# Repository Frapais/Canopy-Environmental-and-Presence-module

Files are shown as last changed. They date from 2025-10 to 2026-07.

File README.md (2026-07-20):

# Canopy — Environmental & Presence Module

**Canopy** is an expansion module from the **SprigStack** ecosystem. It plugs directly onto the pin headers of a [**Sprig-C3**](https://github.com/Frapais/Sprig-C3) ESP32-C3 development board and turns it into a complete, battery-powered environmental and presence sensor for Home Assistant.

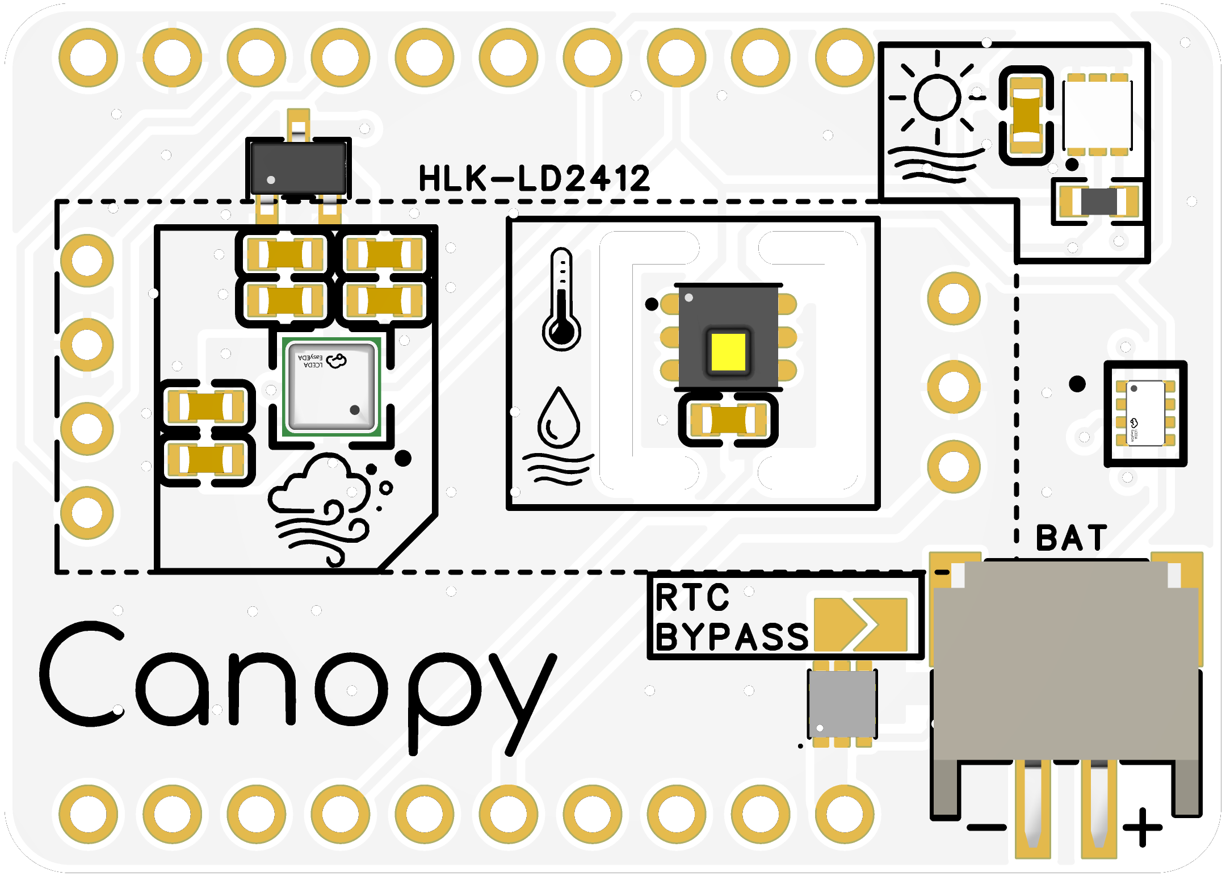
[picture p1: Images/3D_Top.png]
Canopy top side
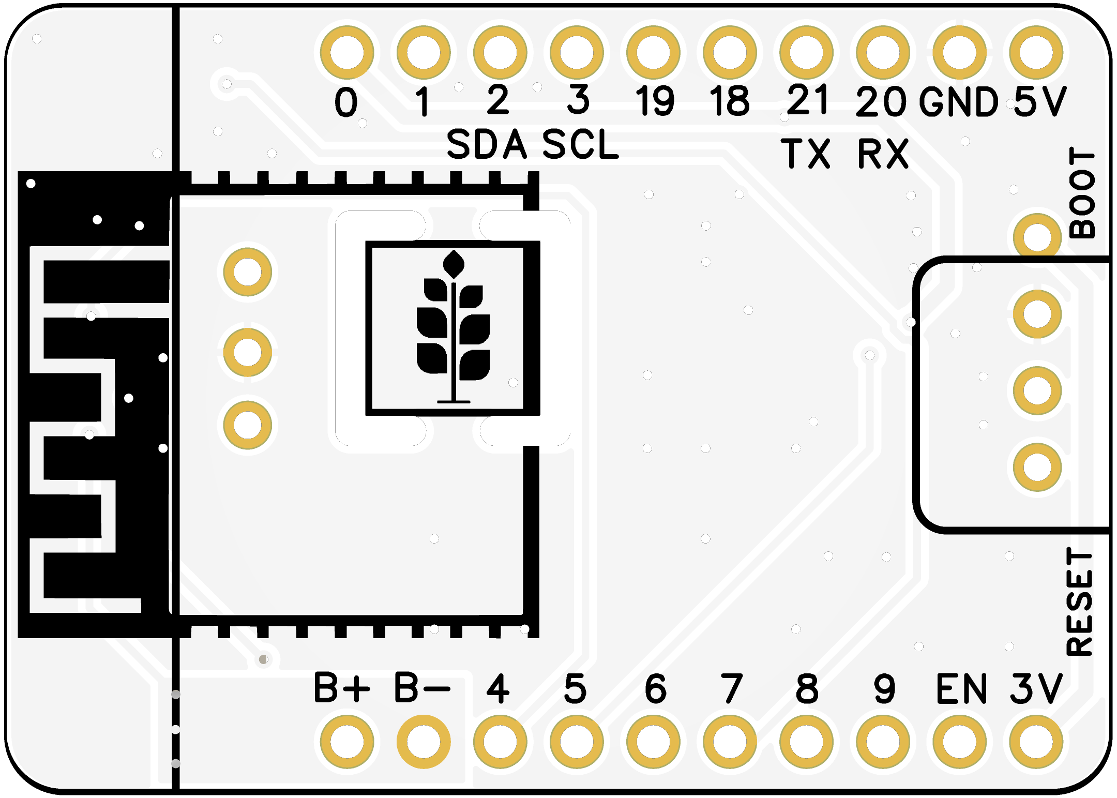
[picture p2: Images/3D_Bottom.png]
Canopy bottom side
|  |  |
| --- | --- |
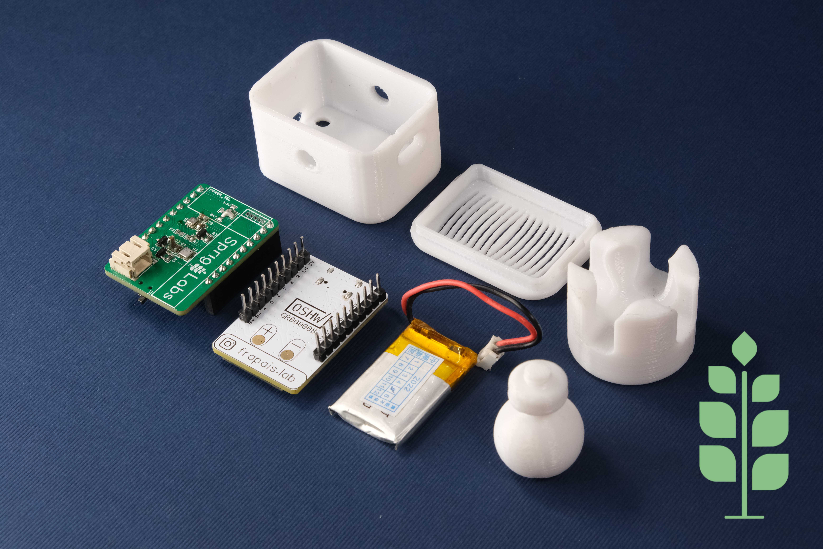
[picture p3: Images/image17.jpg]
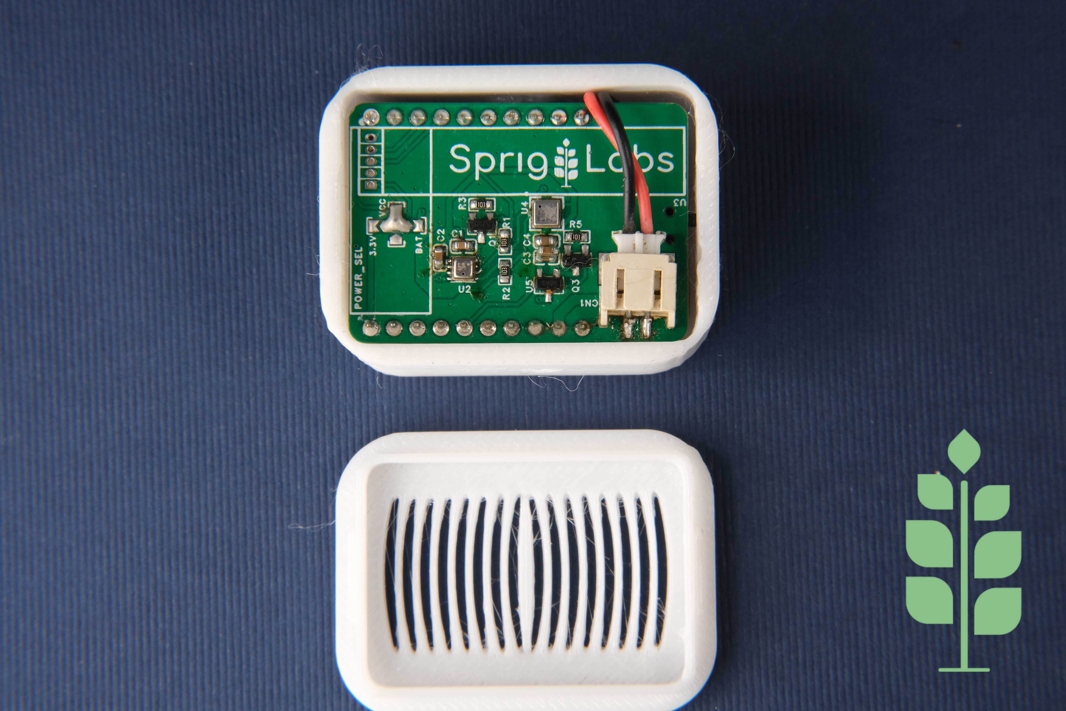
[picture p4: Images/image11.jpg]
|  |  |

---

## Contents

- [Features](#features)
- [Sensors](#sensors)
- [Pinout](#pinout)
- [Power management](#power-management)
- [Real-time clock](#real-time-clock)
- [Enclosure](#enclosure)
- [Firmware](#firmware)
  - [ESPHome setup](#esphome-setup)
  - [MQTT setup](#mqtt-setup)
- [Repository structure](#repository-structure)
- [Availability](#availability)
- [Support](#support)
- [License](#license)

---

## Features

- Air temperature and relative humidity
- Air quality: **AQI**, **eCO₂** and **TVOC**
- Ambient light in lux
- 24 GHz **mmWave human presence** detection, including stationary targets (NOT implemented yet)
- On-board **real-time clock** with a solder-jumper bypass (NOT implemented yet)
- Independent **power gating** of every sensor via GPIO, for true low-power deep-sleep operation
- Secondary **battery connector** passed through to the Sprig-C3
- Stacks directly onto the Sprig-C3 / C6 headers — no wiring
- Designed to fit the 3D-printed ball-joint enclosure included in this repo

---

## Sensors

| Function | Part | Interface | Address | Power enable |
| --- | --- | --- | --- | --- |
| Air temperature & humidity | HDC1080 | I²C | `0x40` | GPIO **8** |
| Air quality (AQI / eCO₂ / TVOC) | ENS160 | I²C | `0x53` | GPIO **0** |
| Ambient light | VEML6030 | I²C | `0x48` | GPIO **7** |
| Human presence | HLK-LD2412 | UART | — | <!-- TODO: enable pin, or always-on --> |
| Real-time clock | <!-- TODO: part number --> | I²C | <!-- TODO --> | always on (see [RTC](#real-time-clock)) |
| Battery gauge | MAX17048 *(on the Sprig-C3)* | I²C | `0x36` | always on |

> The VEML6030 responds at `0x48` when its ADDR pin is pulled high and `0x10` when pulled low. The ENS160 responds at `0x53` or `0x52` in the same way. Run an I²C scan on first power-up to confirm what your board reports.

---

## Pinout

Canopy uses the following Sprig-C3 pins. **Every other pin on the headers is passed straight through** and remains free for your own use.

| Sprig-C3 pin | Used for |
| --- | --- |
| 2 | I²C **SDA** — all I²C sensors + RTC + fuel gauge |
| 3 | I²C **SCL** |
| 8 | HDC1080 power enable (active high) |
| 0 | ENS160 power enable (active high) |
| 7 | VEML6030 power enable (active high) |
| 20 / 21 | HLK-LD2412 **RX / TX** <!-- TODO: confirm orientation --> |
| 3V3, GND | Module supply |



### Strapping-pin note

GPIO **8** is a strapping pin on the ESP32-C3 and must read high at reset. It is an input for the first few hundred milliseconds after power-up, so if the HDC1080 rail pulls it low during that window the board will not boot. GPIO **9** (BOOT) and GPIO **2** (SDA, held high by the bus pull-ups) are the other two strapping pins. GPIO **0** and **7** are unrestricted.

---

## Power management

Each environmental sensor is fed from a GPIO rather than the main 3V3 rail, so firmware can cut its supply entirely before entering deep sleep. Combined with the Sprig-C3's ~66 µA idle draw, this is what makes multi-month battery life realistic.

```
digitalWrite(PWR_HDC1080,  HIGH);   // GPIO 8
digitalWrite(PWR_ENS160,   HIGH);   // GPIO 0
digitalWrite(PWR_VEML6030, HIGH);   // GPIO 7
delay(50);                          // let the rails settle before I²C
```

Two things to keep in mind:

- **The ENS160 needs warm-up time.** Its gas readings are only meaningful after roughly 3 minutes of continuous operation, and the sensor requires a one-time 24-hour burn-in when new. Power-gating it on a short cycle means it never leaves warm-up, so keep it powered for update intervals below ~10 minutes.
- **GPIO 7 and 8 are not RTC-capable** on the ESP32-C3, so they float during deep sleep. Call `gpio_deep_sleep_hold_en()` and `gpio_hold_en()` on them before sleeping, or those rails will drift.

---

## Real-time clock (NOT implemented yet)

Canopy carries an on-board RTC so the node can enter deep-sleep cycles that completely shut down the system, therefore achieving great battery life. <!-- TODO: solder the RTC and test its functionality -->

The **RTC BYPASS** solder jumper on the board.

---

## Enclosure

The `Enclosure/` folder contains a two-part sensor housing and a matching ball-joint mount, so the module can be aimed at whatever the mmWave sensor should be watching.

| Part | File | Size (mm) |
| --- | --- | --- |
| Enclosure body | `Env sensor enclosure - Body.stl` | 32.1 × 42.8 × 24.4 |
| Enclosure lid | `Env sensor enclosure - Lid.stl` | 32.1 × 42.8 × 6.0 |
| Ball (attaches to body) | `Ball Joint - ball.stl` | 20.0 × 20.0 × 29.4 |
| Mount cup (attaches to surface) | `Ball Joint - mount.stl` | 30.0 × 30.0 × 23.0 |
| Full assembly | `Assembly.step` | — |

### Printing

| Setting | Recommendation |
| --- | --- |
| Material | PLA or PETG |
| Layer height | 0.1-0.20 mm |
| Walls | 2 perimeters |
| Infill | 10% |
| Supports | Not required for the body or lid; the ball joint prints best stem-up |

The vented face of the lid must stay clear — it is the airflow path to the HDC1080 and ENS160. Do not fill it with supports or paint over it. The lid is deliberately thin in front of the mmWave module so the 24 GHz signal passes through; avoid metallic or carbon-filled filaments, which will block it.

<!-- TODO: hardware list — screw size and count for lid, whether the ball is a friction fit or needs a screw -->

---

## Firmware

Two paths are supported. ESPHome is the fastest way to get entities into Home Assistant; the Arduino/MQTT sketch is for anyone who wants full control or is not running ESPHome.

### ESPHome setup

**Requirements:** Home Assistant with the ESPHome add-on installed.

1. Plug the Canopy onto the Sprig-C3, then connect the Sprig-C3 to the machine running Home Assistant while holding **BOOT** (only needed the first time).
2. In ESPHome, add a new device and pick **ESP32-C3**.
3. Replace the generated YAML with the contents of [`Firmware/canopy-test.yaml`](Firmware/canopy-test.yaml).
4. Set `wifi_ssid` and `wifi_password` in your ESPHome `secrets.yaml`.
5. Upload, selecting the port that appears as a **USB JTAG** device.
6. Configure the newly discovered device from Home Assistant settings.

### MQTT setup

**Requirements:** an MQTT broker (tested with Mosquitto) and the Home Assistant MQTT integration, plus the Arduino IDE.

1. Open [`Firmware/Canopy_C3_mqtt/Canopy_C3_mqtt.ino`](Firmware/Canopy_C3_mqtt/Canopy_C3_mqtt.ino).
2. Install the required libraries from the Library Manager:
   - PubSubClient (Nick O'Leary)
   - ArduinoJson v6.x (Benoit Blanchon)
   - Adafruit MAX1704X
   - ClosedCube HDC1080
   - SparkFun Indoor Air Quality Sensor — ENS160
   - SparkFun Ambient Light Sensor (VEML6030)
3. Select **ESP32C3 Dev Module** as the board and upload.
4. On first boot the node opens an open WiFi access point named **`Canopy-Setup`**. Join it from a phone or laptop; the captive portal appears automatically, or browse to `http://192.168.4.1`.
5. Enter your WiFi credentials and MQTT broker address, port, username and password, then save. The node reboots and connects.
6. Entities appear in Home Assistant automatically through MQTT discovery — no manual topic entry needed. All readings are published every 60 seconds to `canopy/<device-id>/state` as a single JSON payload, with availability on `canopy/<device-id>/status`.

Hold the **BOOT** button for 5 seconds at any point to erase the stored credentials and reopen the setup portal.

---

## Repository structure

```
Canopy-Environmental-and-Presence-module/
├── README.md
├── LICENSE
├── PCB/
│   ├── Canopy-schematic.pdf          # exported schematic, readable without EDA software
│   ├── Canopy-BOM.csv                # bill of materials
│   ├── Gerbers/                      # zipped fabrication files
│   ├── EasyEDA/                      # source project files
│   └── Images/                       # renders: top, bottom, pinout
├── Firmware/
│   ├── ESPHome/
│   │   └── canopy.yaml               # full ESPHome configuration
│   └── MQTT/
│       └── Canopy_C3_mqtt/
│           └── Canopy_C3_mqtt.ino    # standalone Arduino sketch with setup portal
└── Enclosure/
    ├── Env sensor enclosure - Body.stl
    ├── Env sensor enclosure - Lid.stl
    ├── Ball Joint - ball.stl
    ├── Ball Joint - mount.stl
    ├── Assembly.step
    └── Images/                       # renders of the assembled unit
```

---

## Availability

Assembled Canopy modules and Sprig-C3 boards are available from [Tindie](https://www.tindie.com/products/spriglabs/canopy-smart-environmental-sensor/), [Lectronz](https://lectronz.com/products/canopy-smart-environmental-sensor), and the [Sprig Labs store](https://sprig-labs.com/canopy).

---

## Support

If you find this project useful, consider supporting its development:

- [PayPal](https://www.paypal.com/paypalme/kostasparaskevas)
- [Buy Me a Coffee](https://www.buymeacoffee.com/spriglabs)
- Instagram: [@sprig_labs](https://www.instagram.com/sprig_labs/)
- YouTube: [@sprig_labs](https://www.youtube.com/@sprig_labs)

---

## License

Released under the **GPL-3.0** license. See [LICENSE](LICENSE).

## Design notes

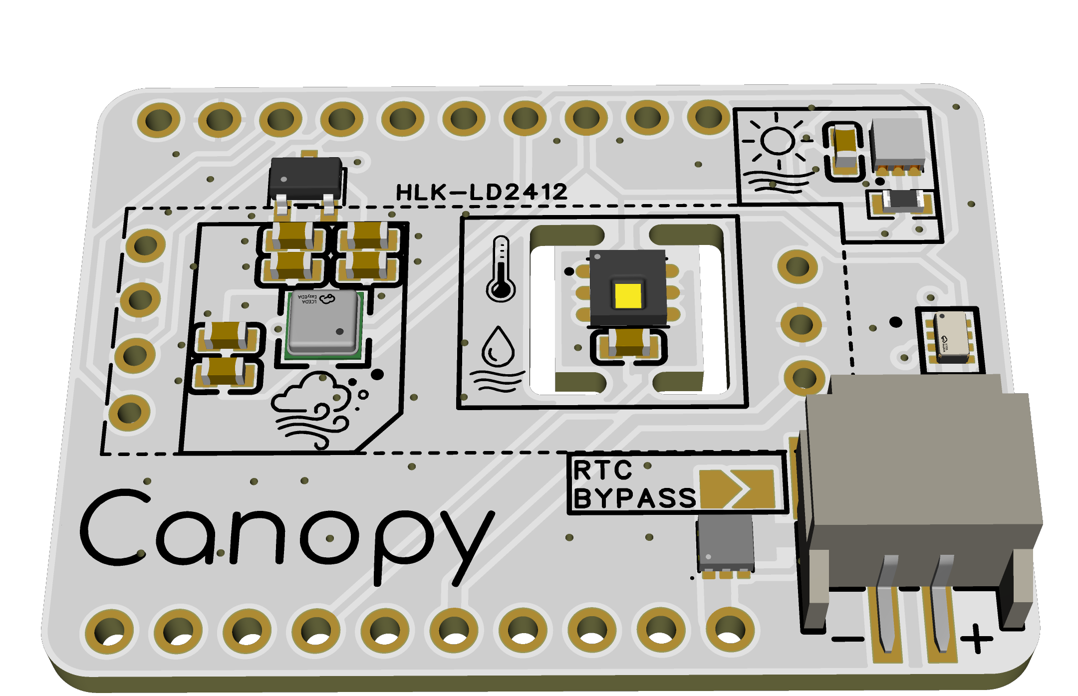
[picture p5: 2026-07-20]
Images/3D.png

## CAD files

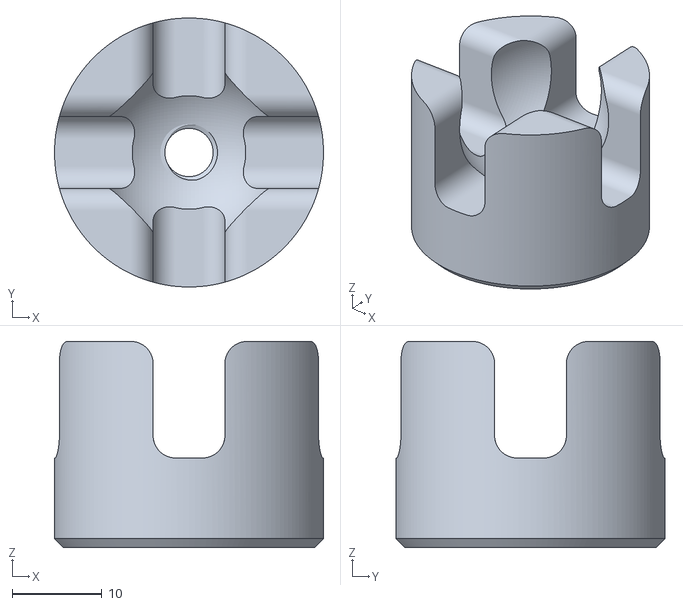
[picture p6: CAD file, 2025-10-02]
Enclosure/Ball Joint - mount.stl
30.0 x 30.0 x 23.0

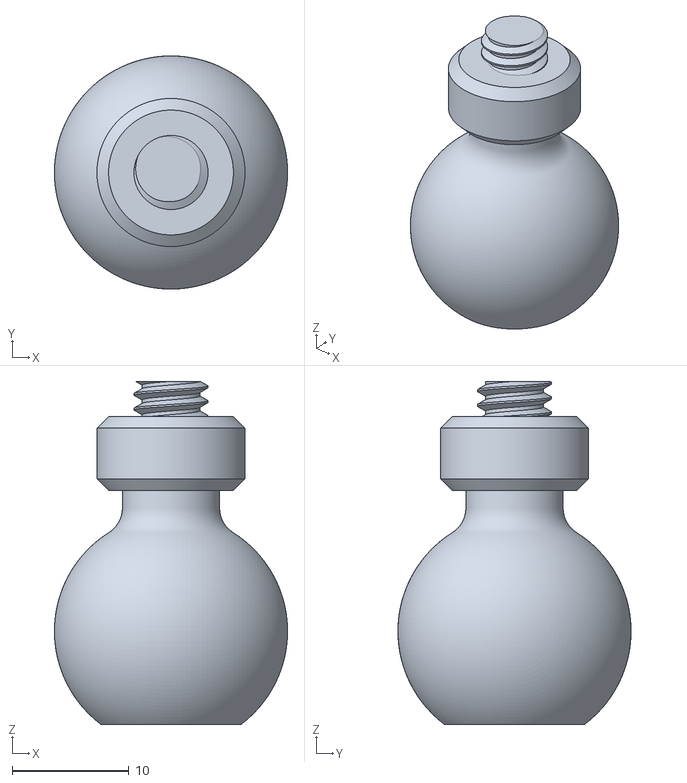
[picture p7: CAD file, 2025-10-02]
Enclosure/Ball Joint - ball.stl
20.0 x 20.0 x 29.4

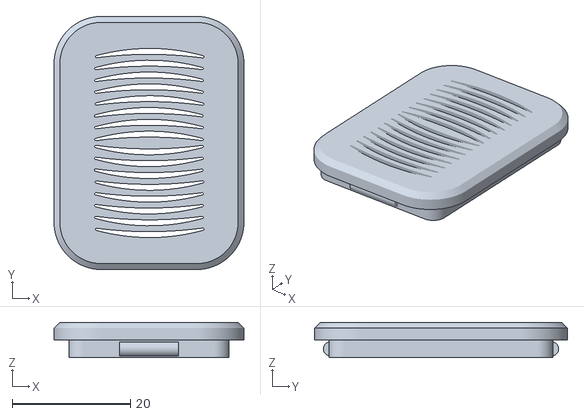
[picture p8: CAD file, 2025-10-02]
Enclosure/Env sensor enclosure - Lid.stl
32.1 x 42.8 x 6.00

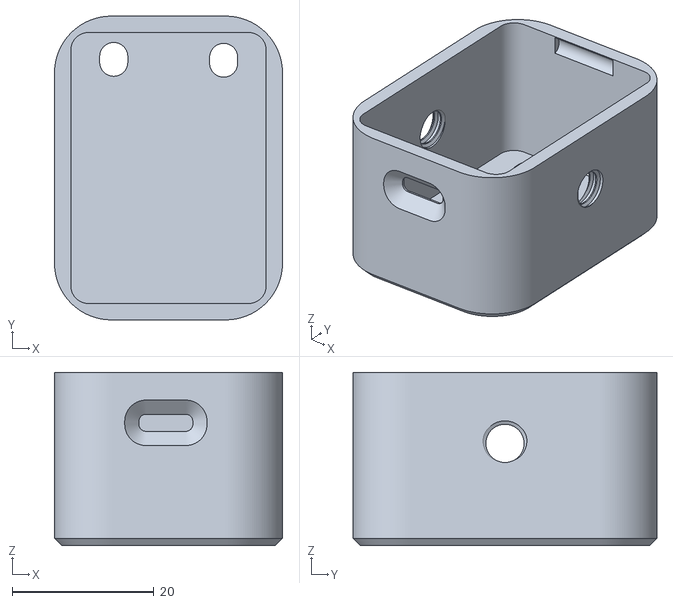
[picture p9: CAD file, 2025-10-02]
Enclosure/Env sensor enclosure - Body.stl
32.1 x 42.8 x 24.4

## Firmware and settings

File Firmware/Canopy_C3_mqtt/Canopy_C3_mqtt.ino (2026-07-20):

/*
 * Canopy + Sprig-C3 — MQTT environmental node
 * ------------------------------------------------------------------
 * Hardware:
 *   Sprig-C3 (ESP32-C3) + Canopy expansion PCB
 *   I2C bus on SDA=GPIO2, SCL=GPIO3
 *     0x36  MAX17048  fuel gauge   (on the Sprig-C3 itself)
 *     0x40  HDC1080   temp / RH    (power via GPIO8)
 *     0x53  ENS160    eCO2 / TVOC  (power via GPIO0)
 *     0x48  VEML6030  ambient lux  (power via GPIO7)
 *
 * Behaviour:
 *   First boot (or after factory reset) -> opens the "Canopy-Setup" AP with a
 *   captive portal at 192.168.4.1 where the user enters WiFi + MQTT details.
 *   Credentials are stored in NVS; on later boots the node connects, publishes
 *   Home Assistant MQTT discovery, then publishes all readings every 60 s.
 *
 *   Hold BOOT (GPIO9) for 5 s at any time to wipe credentials and reopen
 *   the setup portal.
 *
 * Required libraries (Library Manager names):
 *   PubSubClient                        by Nick O'Leary
 *   ArduinoJson  (v6.x)                 by Benoit Blanchon
 *   Adafruit MAX1704X                   by Adafruit
 *   ClosedCube HDC1080                  by ClosedCube
 *   SparkFun Ambient Light Sensor Arduino Library (VEML6030)
 *
 *   The ENS160 is driven by direct register access (see the ENS160 section
 *   below) rather than through a library, so its full status word can be
 *   reported instead of a pass/fail boolean.
 *
 * Board: "ESP32C3 Dev Module" (esp32 core 2.0.x / 3.x)
 */

#include <WiFi.h>
#include <WebServer.h>
#include <DNSServer.h>
#include <Preferences.h>
#include <PubSubClient.h>
#include <ArduinoJson.h>
#include <Wire.h>

#include "Adafruit_MAX1704X.h"
#include "ClosedCube_HDC1080.h"
#include "SparkFun_VEML6030_Ambient_Light_Sensor.h"

// ------------------------------------------------------------------
//  User-tunable settings
// ------------------------------------------------------------------
#define SDA_PIN            2
#define SCL_PIN            3

#define PWR_HDC1080        8      // GPIO powering the HDC1080
#define PWR_ENS160         0      // GPIO powering the ENS160
#define PWR_VEML6030       7      // GPIO powering the VEML6030

#define BOOT_BTN           9      // Sprig-C3 BOOT button, active low
#define BOOT_HOLD_MS       5000   // hold time for factory reset

#define PUBLISH_INTERVAL   60000UL   // ms between publishes
#define WIFI_TIMEOUT_MS    20000UL   // give up and open the portal after this

#define VEML6030_ADDR      0x48   // 0x48 if ADDR is high, 0x10 if ADDR is low
#define ENS160_ADDR        0x53   // 0x53 if ADDR is high, 0x52 if ADDR is low

// The ENS160 needs ~3 min of warm-up after every power-up before its gas
// readings mean anything, so with a 60 s interval it is left powered on.
// Set this to false only if you switch to a long deep-sleep cycle.
#define KEEP_SENSORS_POWERED   true

// Print the full ENS160 register dump on every publish cycle.
// Set to false once the sensor is behaving.
#define ENS_VERBOSE            true

const char *AP_SSID = "Canopy-Setup";
const char *AP_PASS = "";          // open AP; set an 8+ char password to secure it
const char *FW_VERSION = "1.0";

// ------------------------------------------------------------------
//  Globals
// ------------------------------------------------------------------
Adafruit_MAX17048   maxlipo;
ClosedCube_HDC1080  hdc1080;
SparkFun_Ambient_Light veml(VEML6030_ADDR);

WiFiClient   wifiClient;
PubSubClient mqtt(wifiClient);
WebServer    server(80);
DNSServer    dnsServer;
Preferences  prefs;

// stored configuration
String cfgSsid, cfgPass, cfgMqttHost, cfgMqttUser, cfgMqttPass;
int    cfgMqttPort = 1883;
String cfgDeviceName = "Canopy";

// runtime state
bool  portalMode      = false;
bool  discoverySent   = false;
bool  hdcOk = false, ensOk = false, vemlOk = false, fuelOk = false;
char  devUniqueID[32];
String baseTopic, stateTopic, availTopic, deviceIP;
unsigned long lastPublish = 0;
unsigned long bootPressStart = 0;
float vemlGain = 0.125;     // low gain suits indoor + daylight without saturating
int   vemlIntegTime = 100;  // ms

// ------------------------------------------------------------------
//  Sensor power control
// ------------------------------------------------------------------
void sensorsPower(bool on) {
  digitalWrite(PWR_HDC1080,  on ? HIGH : LOW);
  digitalWrite(PWR_ENS160,   on ? HIGH : LOW);
  digitalWrite(PWR_VEML6030, on ? HIGH : LOW);
  if (on) delay(50);   // let the rails settle before touching I2C
}

// ------------------------------------------------------------------
//  ENS160 register-level access
//  Datasheet register map, all multi-byte values little-endian.
// ------------------------------------------------------------------
#define ENS_PART_ID   0x00   // 2 bytes, should read 0x0160
#define ENS_OPMODE    0x10   // 0x00 deep sleep, 0x01 idle, 0x02 standard, 0xF0 reset
#define ENS_CONFIG    0x11
#define ENS_TEMP_IN   0x13   // 2 bytes, (degC + 273.15) * 64
#define ENS_RH_IN     0x15   // 2 bytes, %RH * 512
#define ENS_STATUS    0x20
#define ENS_DATA_AQI  0x21
#define ENS_DATA_TVOC 0x22   // 2 bytes, ppb
#define ENS_DATA_ECO2 0x24   // 2 bytes, ppm
#define ENS_DATA_T    0x30   // 2 bytes, compensation readback
#define ENS_DATA_RH   0x32   // 2 bytes, compensation readback

uint8_t ensAddr = ENS160_ADDR;

bool ensAcks(uint8_t addr) {
  Wire.beginTransmission(addr);
  return Wire.endTransmission() == 0;
}

bool ensRead(uint8_t reg, uint8_t *buf, uint8_t len) {
  Wire.beginTransmission(ensAddr);
  Wire.write(reg);
  if (Wire.endTransmission(false) != 0) return false;
  if (Wire.requestFrom((int)ensAddr, (int)len) != (int)len) return false;
  for (uint8_t i = 0; i < len; i++) buf[i] = Wire.read();
  return true;
}

uint8_t ensRead8(uint8_t reg) {
  uint8_t v = 0;
  ensRead(reg, &v, 1);
  return v;
}

uint16_t ensRead16(uint8_t reg) {
  uint8_t b[2] = {0, 0};
  ensRead(reg, b, 2);
  return (uint16_t)b[0] | ((uint16_t)b[1] << 8);
}

bool ensWrite8(uint8_t reg, uint8_t val) {
  Wire.beginTransmission(ensAddr);
  Wire.write(reg);
  Wire.write(val);
  return Wire.endTransmission() == 0;
}

bool ensWrite16(uint8_t reg, uint16_t val) {
  Wire.beginTransmission(ensAddr);
  Wire.write(reg);
  Wire.write((uint8_t)(val & 0xFF));
  Wire.write((uint8_t)(val >> 8));
  return Wire.endTransmission() == 0;
}

// Feed temperature / humidity to the ENS160 for gas compensation.
void ensSetCompensation(float tempC, float rhPct) {
  ensWrite16(ENS_TEMP_IN, (uint16_t)((tempC + 273.15f) * 64.0f));
  ensWrite16(ENS_RH_IN,   (uint16_t)(rhPct * 512.0f));
}

const char *ensValidityText(uint8_t v) {
  switch (v) {
    case 0: return "normal";
    case 1: return "warm-up";
    case 2: return "initial start-up";
    default: return "invalid output";
  }
}

// Put the part into standard measuring mode from whatever state it is in.
bool ensStartStandard() {
  ensWrite8(ENS_OPMODE, 0xF0);   // reset
  delay(20);
  ensWrite8(ENS_OPMODE, 0x01);   // idle
  delay(20);
  bool ok = ensWrite8(ENS_OPMODE, 0x02);   // standard
  delay(50);
  return ok && ensRead8(ENS_OPMODE) == 0x02;
}

void ens160Diagnostics() {
  Serial.println(F("---------- ENS160 diagnostics ----------"));
  Serial.print(F("  uptime           : "));
  Serial.print(millis() / 1000);
  Serial.println(F(" s since boot"));

  // 1. Does anything answer on the bus?
  if (!ensAcks(ensAddr)) {
    Serial.print(F("  I2C              : NO ACK at 0x"));
    Serial.println(ensAddr, HEX);
    uint8_t alt = (ensAddr == 0x53) ? 0x52 : 0x53;
    Serial.print(F("  alternate 0x"));
    Serial.print(alt, HEX);
    Serial.println(ensAcks(alt) ? F("     : RESPONDS -> set ENS160_ADDR to this")
                                : F("     : no response either"));
    Serial.println(F("  => The chip is not on the bus. Check that GPIO0 is high,"));
    Serial.println(F("     that the 3V3 rail at the sensor is really 3.3 V under"));
    Serial.println(F("     load, and that SDA/SCL pull-ups are present."));
    Serial.println(F("----------------------------------------"));
    return;
  }
  Serial.print(F("  I2C              : ACK at 0x"));
  Serial.println(ensAddr, HEX);

  // 2. Is it actually an ENS160?
  uint16_t pid = ensRead16(ENS_PART_ID);
  Serial.print(F("  PART_ID          : 0x"));
  Serial.print(pid, HEX);
  Serial.println(pid == 0x0160 ? F("  (correct)")
                               : F("  (EXPECTED 0x160 - wrong device or bad reads)"));

  // 3. What mode is it in?
  uint8_t opmode = ensRead8(ENS_OPMODE);
  Serial.print(F("  OPMODE           : 0x"));
  Serial.print(opmode, HEX);
  switch (opmode) {
    case 0x00: Serial.println(F("  DEEP SLEEP - not measuring")); break;
    case 0x01: Serial.println(F("  IDLE - not measuring")); break;
    case 0x02: Serial.println(F("  STANDARD - measuring")); break;
    case 0xF0: Serial.println(F("  RESET")); break;
    default:   Serial.println(F("  unexpected value")); break;
  }

  // 4. Decode the status word.
  uint8_t st = ensRead8(ENS_STATUS);
  uint8_t validity = (st >> 2) & 0x03;
  Serial.print(F("  STATUS           : 0x"));
  if (st < 0x10) Serial.print('0');
  Serial.println(st, HEX);
  Serial.print(F("    STATAS (running) : ")); Serial.println((st & 0x80) ? F("yes") : F("NO"));
  Serial.print(F("    STATER (error)   : ")); Serial.println((st & 0x40) ? F("YES") : F("no"));
  Serial.print(F("    VALIDITY         : ")); Serial.print(validity);
  Serial.print(F(" = ")); Serial.println(ensValidityText(validity));
  Serial.print(F("    NEWDAT           : ")); Serial.println((st & 0x02) ? F("yes") : F("no"));
  Serial.print(F("    NEWGPR           : ")); Serial.println((st & 0x01) ? F("yes") : F("no"));

  // 5. Raw measurement registers, regardless of NEWDAT.
  Serial.print(F("  DATA_AQI         : ")); Serial.println(ensRead8(ENS_DATA_AQI) & 0x07);
  Serial.print(F("  DATA_TVOC        : ")); Serial.print(ensRead16(ENS_DATA_TVOC)); Serial.println(F(" ppb"));
  Serial.print(F("  DATA_ECO2        : ")); Serial.print(ensRead16(ENS_DATA_ECO2)); Serial.println(F(" ppm"));

  // 6. Confirm the compensation values actually landed.
  uint16_t rawT = ensRead16(ENS_DATA_T);
  uint16_t rawH = ensRead16(ENS_DATA_RH);
  Serial.print(F("  comp readback    : "));
  Serial.print(rawT / 64.0f - 273.15f, 1); Serial.print(F(" C, "));
  Serial.print(rawH / 512.0f, 1); Serial.println(F(" %RH"));

  // 7. Plain-language conclusion.
  Serial.print(F("  => "));
  if (st == 0x00 || st == 0xFF) {
    Serial.println(F("Status reads all-zero/all-ones: the chip acknowledges its"));
    Serial.println(F("     address but is not responding properly. Almost always a"));
    Serial.println(F("     power problem - see the GPIO0 note in the README."));
  } else if (opmode != 0x02) {
    Serial.println(F("Not in STANDARD mode, so it will never produce data."));
    Serial.println(F("     The mode write was lost, usually because the rail dropped."));
  } else if (st & 0x40) {
    Serial.println(F("Error flag set. Power-cycle GPIO0 and re-check."));
  } else if (validity == 3) {
    Serial.println(F("Invalid output. Usually a brown-out mid-measurement or a"));
    Serial.println(F("     sensor element fault."));
  } else if (validity == 1) {
    Serial.println(F("Warming up. Gas data becomes valid ~3 min after power-on."));
  } else if (validity == 2) {
    Serial.println(F("Initial start-up. This lasts up to 1 hour and happens once"));
    Serial.println(F("     in the sensor's life. Values are published but coarse."));
  } else {
    Serial.println(F("Operating normally."));
  }
  Serial.println(F("----------------------------------------"));
}

// ------------------------------------------------------------------
//  Sensor init
// ------------------------------------------------------------------
void initSensors() {
  // --- MAX17048 fuel gauge (always powered, lives on the Sprig-C3) ---
  fuelOk = maxlipo.begin(&Wire);
  if (fuelOk) {
    Serial.print(F("MAX17048 chip ID: 0x"));
    Serial.println(maxlipo.getChipID(), HEX);
  } else {
    Serial.println(F("MAX17048 not found."));
  }

  // --- HDC1080 ---
  hdc1080.begin(0x40);
  delay(20);
  float t = hdc1080.readTemperature();
  hdcOk = !isnan(t) && t > -40.0 && t < 125.0;
  Serial.println(hdcOk ? F("HDC1080 ready.") : F("HDC1080 not responding."));

  // --- VEML6030 ---
  vemlOk = veml.begin();
  if (vemlOk) {
    veml.setGain(vemlGain);
    veml.setIntegTime(vemlIntegTime);
    Serial.println(F("VEML6030 ready."));
  } else {
    Serial.println(F("VEML6030 not responding."));
  }

  // --- ENS160 ---
  // Probe the configured address, then the alternate one, so a mis-strapped
  // ADDR pin shows up as a clear message rather than silence.
  if (!ensAcks(ensAddr)) {
    uint8_t alt = (ensAddr == 0x53) ? 0x52 : 0x53;
    if (ensAcks(alt)) {
      Serial.print(F("ENS160 answered at 0x"));
      Serial.print(alt, HEX);
      Serial.println(F(" instead of the configured address; using it."));
      ensAddr = alt;
    }
  }
  ensOk = ensAcks(ensAddr);
  if (ensOk) {
    if (!ensStartStandard())
      Serial.println(F("ENS160: could not enter STANDARD mode."));
  }
  ens160Diagnostics();
}

void i2cScan() {
  Serial.println(F("I2C scan:"));
  for (uint8_t a = 1; a < 127; a++) {
    Wire.beginTransmission(a);
    if (Wire.endTransmission() == 0) {
      Serial.print(F("  found 0x"));
      Serial.println(a, HEX);
    }
  }
}

// ------------------------------------------------------------------
//  Unique ID + topics
// ------------------------------------------------------------------
void buildIdentity() {
  byte mac[6];
  WiFi.macAddress(mac);
  snprintf(devUniqueID, sizeof(devUniqueID), "canopy%02X%02X%02X",
           mac[3], mac[4], mac[5]);

  baseTopic  = String("canopy/") + devUniqueID;
  stateTopic = baseTopic + "/state";
  availTopic = baseTopic + "/status";

  Serial.print(F("Device ID: "));
  Serial.println(devUniqueID);
}

// ------------------------------------------------------------------
//  Configuration portal
// ------------------------------------------------------------------
String portalPage() {
  String p = F("<!DOCTYPE html><html><head><meta charset='utf-8'>"
               "<meta name='viewport' content='width=device-width,initial-scale=1'>"
               "<title>Canopy Setup</title><style>"
               "body{font-family:system-ui,sans-serif;margin:0;padding:24px;"
               "background:#12161a;color:#e8eef2}"
               ".c{max-width:420px;margin:0 auto}"
               "h1{font-size:20px;margin:0 0 4px}p.s{color:#8fa3b0;margin:0 0 20px;font-size:14px}"
               "label{display:block;margin:14px 0 4px;font-size:13px;color:#a8bcc8}"
               "input{width:100%;box-sizing:border-box;padding:10px;border-radius:6px;"
               "border:1px solid #2b343c;background:#1a2027;color:#e8eef2;font-size:15px}"
               "button{width:100%;margin-top:22px;padding:12px;border:0;border-radius:6px;"
               "background:#3d9970;color:#fff;font-size:16px;font-weight:600}"
               "</style></head><body><div class='c'>"
               "<h1>Canopy Setup</h1><p class='s'>WiFi and MQTT broker details</p>"
               "<form method='POST' action='/save'>");
  p += F("<label>Device name</label><input name='dev_name' value='Canopy' maxlength='24'>");
  p += F("<label>WiFi SSID</label><input name='wifi_ssid' maxlength='32' required>");
  p += F("<label>WiFi password</label><input name='wifi_pass' type='password' maxlength='64'>");
  p += F("<label>MQTT broker (IP or host)</label><input name='mqtt_host' required>");
  p += F("<label>MQTT port</label><input name='mqtt_port' value='1883'>");
  p += F("<label>MQTT username</label><input name='mqtt_user'>");
  p += F("<label>MQTT password</label><input name='mqtt_pass' type='password'>");
  p += F("<button type='submit'>Save &amp; reboot</button></form></div></body></html>");
  return p;
}

void startConfigPortal() {
  Serial.println(F("Starting configuration portal."));
  portalMode = true;

  WiFi.mode(WIFI_AP);
  WiFi.softAP(AP_SSID, strlen(AP_PASS) ? AP_PASS : NULL);
  IPAddress apIP = WiFi.softAPIP();
  Serial.print(F("Connect to '"));
  Serial.print(AP_SSID);
  Serial.print(F("' then browse to http://"));
  Serial.println(apIP);

  dnsServer.start(53, "*", apIP);   // captive portal redirect

  server.on("/", HTTP_GET, []() { server.send(200, "text/html", portalPage()); });

  server.on("/save", HTTP_POST, []() {
    prefs.begin("canopy", false);
    prefs.putString("wifi_ssid", server.arg("wifi_ssid"));
    prefs.putString("wifi_pass", server.arg("wifi_pass"));
    prefs.putString("mqtt_host", server.arg("mqtt_host"));
    prefs.putInt   ("mqtt_port", server.arg("mqtt_port").toInt() ? server.arg("mqtt_port").toInt() : 1883);
    prefs.putString("mqtt_user", server.arg("mqtt_user"));
    prefs.putString("mqtt_pass", server.arg("mqtt_pass"));
    prefs.putString("dev_name",  server.arg("dev_name").length() ? server.arg("dev_name") : String("Canopy"));
    prefs.end();
    server.send(200, "text/html",
      F("<html><body style='font-family:sans-serif;background:#12161a;color:#e8eef2;padding:40px'>"
        "<h3>Saved. Rebooting…</h3></body></html>"));
    delay(600);
    ESP.restart();
  });

  // anything else -> portal page, so phones pop the captive portal sheet
  server.onNotFound([]() { server.send(200, "text/html", portalPage()); });

  server.begin();
}

void startRuntimeServer() {
  server.on("/", HTTP_GET, []() {
    String p = F("<html><head><meta charset='utf-8'><meta name='viewport' "
                 "content='width=device-width,initial-scale=1'><title>Canopy</title>"
                 "<style>body{font-family:system-ui,sans-serif;background:#12161a;"
                 "color:#e8eef2;padding:24px}code{color:#7fd1a8}</style></head><body>");
    p += "<h2>" + cfgDeviceName + "</h2>";
    p += "<p>ID: <code>" + String(devUniqueID) + "</code></p>";
    p += "<p>Broker: <code>" + cfgMqttHost + ":" + String(cfgMqttPort) + "</code> — " +
         (mqtt.connected() ? "connected" : "disconnected") + "</p>";
    p += "<p>State topic: <code>" + stateTopic + "</code></p>";
    p += "<p>RSSI: " + String(WiFi.RSSI()) + " dBm</p>";
    p += "<p>Sensors: HDC1080 " + String(hdcOk ? "ok" : "fail") +
         " · ENS160 " + String(ensOk ? "ok" : "fail") +
         " · VEML6030 " + String(vemlOk ? "ok" : "fail") + "</p>";
    p += F("<p><a href='/reset' style='color:#e08a8a'>Erase credentials &amp; reboot</a></p>");
    p += F("</body></html>");
    server.send(200, "text/html", p);
  });

  server.on("/reset", HTTP_GET, []() {
    server.send(200, "text/html", F("<html><body>Erasing…</body></html>"));
    prefs.begin("canopy", false);
    prefs.clear();
    prefs.end();
    delay(400);
    ESP.restart();
  });

  server.begin();
}

// ------------------------------------------------------------------
//  Home Assistant MQTT discovery
// ------------------------------------------------------------------
void addDeviceBlock(JsonDocument &doc) {
  JsonObject dev = doc.createNestedObject("dev");
  JsonArray ids = dev.createNestedArray("ids");
  ids.add(devUniqueID);
  dev["name"] = cfgDeviceName;
  dev["mf"]   = "Sprig Labs";
  dev["mdl"]  = "Sprig-C3 + Canopy";
  dev["sw"]   = FW_VERSION;
  dev["cu"]   = String("http://") + deviceIP + "/";
}

void publishDiscovery(const char *key, const char *name, const char *unit,
                      const char *devClass, const char *stateClass,
                      const char *icon = nullptr, bool diagnostic = false) {
  StaticJsonDocument<640> doc;
  char uid[64], topic[160];

  snprintf(uid, sizeof(uid), "%s_%s", devUniqueID, key);
  snprintf(topic, sizeof(topic), "homeassistant/sensor/%s/config", uid);

  doc["name"]     = name;
  doc["uniq_id"]  = uid;
  doc["obj_id"]   = uid;
  doc["stat_t"]   = stateTopic;
  doc["avty_t"]   = availTopic;
  doc["val_tpl"]  = String("{{ value_json.") + key + " }}";
  if (unit)       doc["unit_of_meas"] = unit;
  if (devClass)   doc["dev_cla"]      = devClass;
  if (stateClass) doc["stat_cla"]     = stateClass;
  if (icon)       doc["ic"]           = icon;
  if (diagnostic) doc["ent_cat"]      = "diagnostic";
  doc["exp_aft"] = (PUBLISH_INTERVAL / 1000) * 3;   // mark unavailable after 3 missed cycles
  addDeviceBlock(doc);

  char payload[640];
  size_t n = serializeJson(doc, payload, sizeof(payload));
  if (!mqtt.publish(topic, (const uint8_t *)payload, n, true)) {
    Serial.print(F("Discovery publish failed for "));
    Serial.println(key);
  }
}
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
void loop() {
  // factory-reset long press, works in both modes
  if (digitalRead(BOOT_BTN) == LOW) {
    if (bootPressStart == 0) bootPressStart = millis();
    else if (millis() - bootPressStart >= BOOT_HOLD_MS) {
      Serial.println(F("Factory reset."));
      prefs.begin("canopy", false);
      prefs.clear();
      prefs.end();
      delay(200);
      ESP.restart();
    }
  } else {
    bootPressStart = 0;
  }

  if (portalMode) {
    dnsServer.processNextRequest();
    server.handleClient();
    delay(2);
    return;
  }

  if (WiFi.status() != WL_CONNECTED) {
    Serial.println(F("WiFi lost, reconnecting…"));
    WiFi.reconnect();
    delay(2000);
    return;
  }

  if (!mqtt.connected()) {
    static unsigned long lastAttempt = 0;
    if (millis() - lastAttempt > 5000) {
      lastAttempt = millis();
      mqttConnect();
    }
  } else {
    mqtt.loop();
  }

  server.handleClient();

  if (mqtt.connected() && millis() - lastPublish >= PUBLISH_INTERVAL) {
    lastPublish = millis();
    readAndPublish();
  }
}

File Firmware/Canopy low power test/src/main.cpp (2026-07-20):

/***************************************************************************
  ENS160 - Digital Air Quality Sensor
  
  This is an example for ENS160 basic reading in custom mode
    
  Updated by Sciosense / 25-Nov-2021
 ***************************************************************************/

#include <Wire.h>
// int ArduinoLED = 13;

//-------------------------------------------------------------
//ENS160 related items
//-------------------------------------------------------------
#include "ScioSense_ENS160.h"  // ENS160 library
ScioSense_ENS160      ens160(ENS160_I2CADDR_1);
//ScioSense_ENS160      ens160(ENS160_I2CADDR_1);

/*--------------------------------------------------------------------------
  SETUP function
  initiate sensor
 --------------------------------------------------------------------------*/
void setup() {

  Serial.begin(115200);

  while (!Serial) {}

  Wire.begin(2,3); //Init I2C
  //Switch on LED for init
//   pinMode(ArduinoLED, OUTPUT);
//   digitalWrite(ArduinoLED, LOW);

  Serial.println("------------------------------------------------------------");
  Serial.println("ENS160 - Digital air quality sensor");
  Serial.println();
  Serial.println("Sensor readout in custom mode");
  Serial.println();
  Serial.println("------------------------------------------------------------");
  delay(1000);

  Serial.print("ENS160...");
  bool ok = ens160.begin();
  Serial.println(ens160.available() ? "done." : "failed!");
  if (ens160.available()) {
    // Print ENS160 versions
    Serial.print("\tRev: "); Serial.print(ens160.getMajorRev());
    Serial.print("."); Serial.print(ens160.getMinorRev());
    Serial.print("."); Serial.println(ens160.getBuild());

    Serial.print("\tSTD mode ");
    ens160.setMode(ENS160_OPMODE_STD);
    Serial.println(ens160.setMode(ENS160_OPMODE_STD) ? "done." : "failed!");

    // Set environment data
    ens160.set_envdata(25.0, 50.0);
  }
}

/*--------------------------------------------------------------------------
  MAIN LOOP FUNCTION
  Cylce every 1000ms and perform measurement
 --------------------------------------------------------------------------*/

void loop() {
  
  static int count = 0;
  
  if (ens160.available()) {
    bool newData = ens160.measure(false);
    if (newData) {
      Serial.print("AQI: "); Serial.print(ens160.getAQI());
      Serial.print("\tTVOC: "); Serial.print(ens160.getTVOC()); Serial.print(" ppb");
      Serial.print("\teCO2: "); Serial.print(ens160.geteCO2()); Serial.println(" ppm");
    }
  }
  
  count++;
  if (count >= 10) {
    Serial.println("Putting sensor in deep sleep for 10 seconds...");
    ens160.setMode(ENS160_OPMODE_DEP_SLEEP);
    delay(10000);
    ens160.setMode(ENS160_OPMODE_STD);
    count = 0;  // Reset counter
  }
  
  delay(1000);
}

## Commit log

2025-08-11 Added 3D files and HA config YAML
    [Ball Joint - ball.3mf, Ball Joint - mount.3mf, Env sensor enclosure - Body.3mf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]
2025-10-02 Updated 3D files
    [Ball Joint - ball.3mf, Ball Joint - ball.stl, Ball Joint - mount.3mf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]
2026-07-20 Added low power & Sprig-C6 tests
2026-07-20 Added MQTT code and V2 board images
2026-07-20 Revise README for Canopy module details
    Updated the README to enhance clarity and detail about the Canopy module, including features, sensors, pinout, power management, and setup instructions.
2026-07-20 Fixed ENS160 measurements in MQTT example
    [Canopy_C3_mqtt.ino]
